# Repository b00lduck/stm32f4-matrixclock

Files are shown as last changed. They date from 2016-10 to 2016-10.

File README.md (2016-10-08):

# stm32f4-matrixclock
Use the STM32F4 to drive a large LED matrix with TLC5940

### Port mapping:

 - PA8  GSCLK	common PWM-clock for the TLC5940s    (TIM1 AF1)

 - PC6  BLANK   common BLANK-signal for the TLC5940s (TIM3 AF2)
 - PC7  LATCH   common LATCH-signal for the TLC5940s (TIM3 AF2)
 - PC9  SCK     common LATCH-signal for the TLC5940s (TIM8 AF3)

 - PD12 LED4	discovery board
 - PD13 LED3	discovery board
 - PD14 LED5	discovery board
 - PD15 LED6  	discovery board

 - PE0  SDA_A	Sector A data (DMA)
 - PE1  SDA_B	Sector B data (DMA)
 - PE2  SDA_C	Sector C data (DMA)
 - PE3  SDA_D	Sector D data (DMA)
 - PE4  SDA_E	Sector E data (DMA)
 - PE5  SDA_F	Sector F data (DMA)
 - PE6  SDA_G	Sector G data (DMA)
 - PE7  SDA_H	Sector H data (DMA)

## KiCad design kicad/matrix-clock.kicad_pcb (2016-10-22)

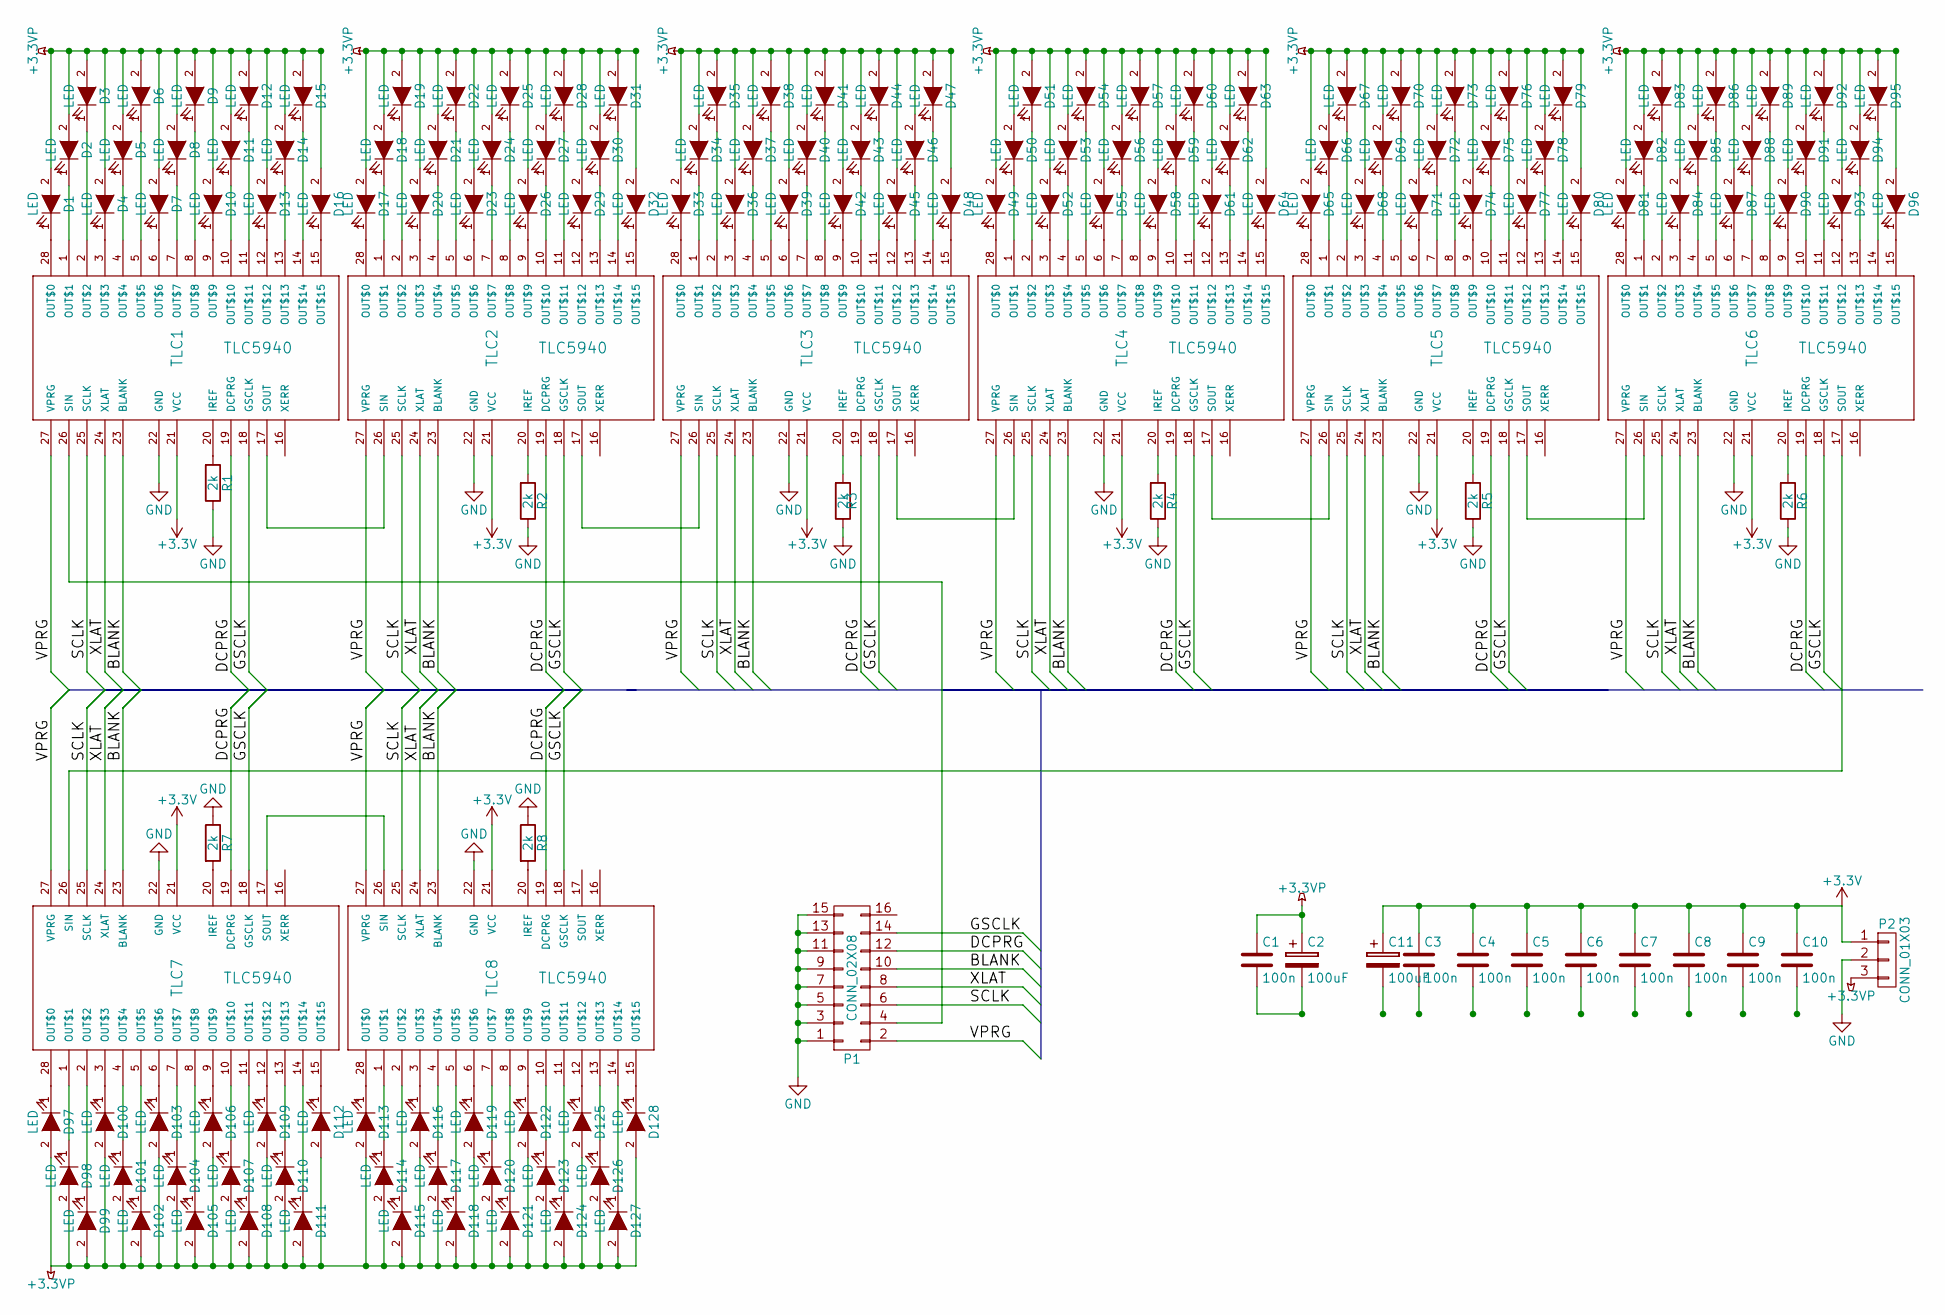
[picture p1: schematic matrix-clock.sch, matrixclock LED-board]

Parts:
C1: 100n; C_0603_HandSoldering
C2, C11: 100uF; TantalC_SizeX_EIA-7343
C3, C4, C5, C6, C7, C8, C9, C10: 100n; C_Disc_D3_P2.5
D1, D2, D3, D4, D5, D6, D7, D8, D9, D10, D11, D12, D13, D14, D15, D16, D17, D18, D19, D20, D21, D22, D23, D24, D25, D26, D27, D28, D29, D30, D31, D32, D33, D34, D35, D36, D37, D38, D39, D40, D41, D42, D43, D44, D45, D46, D47, D48, D49, D50, D51, D52, D53, D54, D55, D56, D57, D58, D59, D60, D61, D62, D63, D64, D65, D66, D67, D68, D69, D70, D71, D72, D73, D74, D75, D76, D77, D78, D79, D80, D81, D82, D83, D84, D85, D86, D87, D88, D89, D90, D91, D92, D93, D94, D95, D96, D97, D98, D99, D100, D101, D102, D103, D104, D105, D106, D107, D108, D109, D110, D111, D112, D113, D114, D115, D116, D117, D118, D119, D120, D121, D122, D123, D124, D125, D126, D127, D128: LED; MENTOR 50.046
P1: CONN_02X08; Pin_Header_Straight_2x08
P2: CONN_01X03; Pin_Header_Straight_1x03
R1, R2, R3, R4, R5, R6, R7, R8: 2k; R_1206_HandSoldering
TLC1, TLC2, TLC3, TLC4, TLC5, TLC6, TLC7, TLC8: TLC5940; TLC5940-HTSSOP-28

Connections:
+3.3VP: C1.1, C2.1, D1.2 (A), D2.2 (A), D3.2 (A), D4.2 (A), D5.2 (A), D6.2 (A), D7.2 (A), D8.2 (A), D9.2 (A), D10.2 (A), D11.2 (A), D12.2 (A), D13.2 (A), D14.2 (A), D15.2 (A), D16.2 (A), D17.2 (A), D18.2 (A), D19.2 (A), D20.2 (A), D21.2 (A), D22.2 (A), D23.2 (A), D24.2 (A), D25.2 (A), D26.2 (A), D27.2 (A), D28.2 (A), D29.2 (A), D30.2 (A), D31.2 (A), D32.2 (A), D33.2 (A), D34.2 (A), D35.2 (A), D36.2 (A), D37.2 (A), D38.2 (A), D39.2 (A), D40.2 (A), D41.2 (A), D42.2 (A), D43.2 (A), D44.2 (A), D45.2 (A), D46.2 (A), D47.2 (A), D48.2 (A), D49.2 (A), D50.2 (A), D51.2 (A), D52.2 (A), D53.2 (A), D54.2 (A), D55.2 (A), D56.2 (A), D57.2 (A), D58.2 (A), D59.2 (A), D60.2 (A), D61.2 (A), D62.2 (A), D63.2 (A), D64.2 (A), D65.2 (A), D66.2 (A), D67.2 (A), D68.2 (A), D69.2 (A), D70.2 (A), D71.2 (A), D72.2 (A), D73.2 (A), D74.2 (A), D75.2 (A), D76.2 (A), D77.2 (A), D78.2 (A), D79.2 (A), D80.2 (A), D81.2 (A), D82.2 (A), D83.2 (A), D84.2 (A), D85.2 (A), D86.2 (A), D87.2 (A), D88.2 (A), D89.2 (A), D90.2 (A), D91.2 (A), D92.2 (A), D93.2 (A), D94.2 (A), D95.2 (A), D96.2 (A), D97.2 (A), D98.2 (A), D99.2 (A), D100.2 (A), D101.2 (A), D102.2 (A), D103.2 (A), D104.2 (A), D105.2 (A), D106.2 (A), D107.2 (A), D108.2 (A), D109.2 (A), D110.2 (A), D111.2 (A), D112.2 (A), D113.2 (A), D114.2 (A), D115.2 (A), D116.2 (A), D117.2 (A), D118.2 (A), D119.2 (A), D120.2 (A), D121.2 (A), D122.2 (A), D123.2 (A), D124.2 (A), D125.2 (A), D126.2 (A), D127.2 (A), D128.2 (A), P2.3
+3V3: C3.1, C4.1, C5.1, C6.1, C7.1, C8.1, C9.1, C10.1, C11.1, P2.1, TLC1.21 (VCC), TLC2.21 (VCC), TLC3.21 (VCC), TLC4.21 (VCC), TLC5.21 (VCC), TLC6.21 (VCC), TLC7.21 (VCC), TLC8.21 (VCC)
/BLANK: P1.10, TLC1.23 (BLANK), TLC2.23 (BLANK), TLC3.23 (BLANK), TLC4.23 (BLANK), TLC5.23 (BLANK), TLC6.23 (BLANK), TLC7.23 (BLANK), TLC8.23 (BLANK)
/DCPRG: P1.12, TLC1.19 (DCPRG), TLC2.19 (DCPRG), TLC3.19 (DCPRG), TLC4.19 (DCPRG), TLC5.19 (DCPRG), TLC6.19 (DCPRG), TLC7.19 (DCPRG), TLC8.19 (DCPRG)
/GSCLK: P1.14, TLC1.18 (GSCLK), TLC2.18 (GSCLK), TLC3.18 (GSCLK), TLC4.18 (GSCLK), TLC5.18 (GSCLK), TLC6.18 (GSCLK), TLC7.18 (GSCLK), TLC8.18 (GSCLK)
/SCLK: P1.6, TLC1.25 (SCLK), TLC2.25 (SCLK), TLC3.25 (SCLK), TLC4.25 (SCLK), TLC5.25 (SCLK), TLC6.25 (SCLK), TLC7.25 (SCLK), TLC8.25 (SCLK)
/VPRG: P1.2, TLC1.27 (VPRG), TLC2.27 (VPRG), TLC3.27 (VPRG), TLC4.27 (VPRG), TLC5.27 (VPRG), TLC6.27 (VPRG), TLC7.27 (VPRG), TLC8.27 (VPRG)
/XLAT: P1.8, TLC1.24 (XLAT), TLC2.24 (XLAT), TLC3.24 (XLAT), TLC4.24 (XLAT), TLC5.24 (XLAT), TLC6.24 (XLAT), TLC7.24 (XLAT), TLC8.24 (XLAT)
unnamed: D1.1 (K), TLC1.28 (OUT$0)
unnamed: D2.1 (K), TLC1.1 (OUT$1)
unnamed: D3.1 (K), TLC1.2 (OUT$2)
unnamed: D4.1 (K), TLC1.3 (OUT$3)
unnamed: D5.1 (K), TLC1.4 (OUT$4)
unnamed: D6.1 (K), TLC1.5 (OUT$5)
unnamed: D7.1 (K), TLC1.6 (OUT$6)
unnamed: D8.1 (K), TLC1.7 (OUT$7)
unnamed: D9.1 (K), TLC1.8 (OUT$8)
unnamed: D10.1 (K), TLC1.9 (OUT$9)
unnamed: D11.1 (K), TLC1.10 (OUT$10)
unnamed: D12.1 (K), TLC1.11 (OUT$11)
unnamed: D13.1 (K), TLC1.12 (OUT$12)
unnamed: D14.1 (K), TLC1.13 (OUT$13)
unnamed: D15.1 (K), TLC1.14 (OUT$14)
unnamed: D16.1 (K), TLC1.15 (OUT$15)
unnamed: D17.1 (K), TLC2.28 (OUT$0)
unnamed: D18.1 (K), TLC2.1 (OUT$1)
unnamed: D19.1 (K), TLC2.2 (OUT$2)
unnamed: D20.1 (K), TLC2.3 (OUT$3)
unnamed: D21.1 (K), TLC2.4 (OUT$4)
unnamed: D22.1 (K), TLC2.5 (OUT$5)
unnamed: D23.1 (K), TLC2.6 (OUT$6)
unnamed: D24.1 (K), TLC2.7 (OUT$7)
unnamed: D25.1 (K), TLC2.8 (OUT$8)
unnamed: D26.1 (K), TLC2.9 (OUT$9)
unnamed: D27.1 (K), TLC2.10 (OUT$10)
unnamed: D28.1 (K), TLC2.11 (OUT$11)
unnamed: D29.1 (K), TLC2.12 (OUT$12)
unnamed: D30.1 (K), TLC2.13 (OUT$13)
unnamed: D31.1 (K), TLC2.14 (OUT$14)
unnamed: D32.1 (K), TLC2.15 (OUT$15)
unnamed: D33.1 (K), TLC3.28 (OUT$0)
unnamed: D34.1 (K), TLC3.1 (OUT$1)
unnamed: D35.1 (K), TLC3.2 (OUT$2)
unnamed: D36.1 (K), TLC3.3 (OUT$3)
unnamed: D37.1 (K), TLC3.4 (OUT$4)
unnamed: D38.1 (K), TLC3.5 (OUT$5)
unnamed: D39.1 (K), TLC3.6 (OUT$6)
unnamed: D40.1 (K), TLC3.7 (OUT$7)
unnamed: D41.1 (K), TLC3.8 (OUT$8)
unnamed: D42.1 (K), TLC3.9 (OUT$9)
unnamed: D43.1 (K), TLC3.10 (OUT$10)
unnamed: D44.1 (K), TLC3.11 (OUT$11)
unnamed: D45.1 (K), TLC3.12 (OUT$12)
unnamed: D46.1 (K), TLC3.13 (OUT$13)
unnamed: D47.1 (K), TLC3.14 (OUT$14)
unnamed: D48.1 (K), TLC3.15 (OUT$15)
unnamed: D49.1 (K), TLC4.28 (OUT$0)
unnamed: D50.1 (K), TLC4.1 (OUT$1)
unnamed: D51.1 (K), TLC4.2 (OUT$2)
unnamed: D52.1 (K), TLC4.3 (OUT$3)
unnamed: D53.1 (K), TLC4.4 (OUT$4)
unnamed: D54.1 (K), TLC4.5 (OUT$5)
unnamed: D55.1 (K), TLC4.6 (OUT$6)
unnamed: D56.1 (K), TLC4.7 (OUT$7)
unnamed: D57.1 (K), TLC4.8 (OUT$8)
unnamed: D58.1 (K), TLC4.9 (OUT$9)
unnamed: D59.1 (K), TLC4.10 (OUT$10)
unnamed: D60.1 (K), TLC4.11 (OUT$11)
unnamed: D61.1 (K), TLC4.12 (OUT$12)
unnamed: D62.1 (K), TLC4.13 (OUT$13)
unnamed: D63.1 (K), TLC4.14 (OUT$14)
unnamed: D64.1 (K), TLC4.15 (OUT$15)
unnamed: D65.1 (K), TLC5.28 (OUT$0)
unnamed: D66.1 (K), TLC5.1 (OUT$1)
unnamed: D67.1 (K), TLC5.2 (OUT$2)
unnamed: D68.1 (K), TLC5.3 (OUT$3)
unnamed: D69.1 (K), TLC5.4 (OUT$4)
unnamed: D70.1 (K), TLC5.5 (OUT$5)
unnamed: D71.1 (K), TLC5.6 (OUT$6)
unnamed: D72.1 (K), TLC5.7 (OUT$7)
unnamed: D73.1 (K), TLC5.8 (OUT$8)
unnamed: D74.1 (K), TLC5.9 (OUT$9)
unnamed: D75.1 (K), TLC5.10 (OUT$10)
unnamed: D76.1 (K), TLC5.11 (OUT$11)
unnamed: D77.1 (K), TLC5.12 (OUT$12)
unnamed: D78.1 (K), TLC5.13 (OUT$13)
unnamed: D79.1 (K), TLC5.14 (OUT$14)
unnamed: D80.1 (K), TLC5.15 (OUT$15)
unnamed: D81.1 (K), TLC6.28 (OUT$0)
unnamed: D82.1 (K), TLC6.1 (OUT$1)
unnamed: D83.1 (K), TLC6.2 (OUT$2)
unnamed: D84.1 (K), TLC6.3 (OUT$3)
unnamed: D85.1 (K), TLC6.4 (OUT$4)
unnamed: D86.1 (K), TLC6.5 (OUT$5)
unnamed: D87.1 (K), TLC6.6 (OUT$6)
unnamed: D88.1 (K), TLC6.7 (OUT$7)
unnamed: D89.1 (K), TLC6.8 (OUT$8)
unnamed: D90.1 (K), TLC6.9 (OUT$9)
unnamed: D91.1 (K), TLC6.10 (OUT$10)
unnamed: D92.1 (K), TLC6.11 (OUT$11)
unnamed: D93.1 (K), TLC6.12 (OUT$12)
unnamed: D94.1 (K), TLC6.13 (OUT$13)
unnamed: D95.1 (K), TLC6.14 (OUT$14)
unnamed: D96.1 (K), TLC6.15 (OUT$15)
unnamed: D97.1 (K), TLC7.28 (OUT$0)
unnamed: D98.1 (K), TLC7.1 (OUT$1)
unnamed: D99.1 (K), TLC7.2 (OUT$2)
unnamed: D100.1 (K), TLC7.3 (OUT$3)
unnamed: D101.1 (K), TLC7.4 (OUT$4)
unnamed: D102.1 (K), TLC7.5 (OUT$5)
unnamed: D103.1 (K), TLC7.6 (OUT$6)
unnamed: D104.1 (K), TLC7.7 (OUT$7)
unnamed: D105.1 (K), TLC7.8 (OUT$8)
unnamed: D106.1 (K), TLC7.9 (OUT$9)
unnamed: D107.1 (K), TLC7.10 (OUT$10)
unnamed: D108.1 (K), TLC7.11 (OUT$11)
unnamed: D109.1 (K), TLC7.12 (OUT$12)
unnamed: D110.1 (K), TLC7.13 (OUT$13)
unnamed: D111.1 (K), TLC7.14 (OUT$14)
unnamed: D112.1 (K), TLC7.15 (OUT$15)
unnamed: D113.1 (K), TLC8.28 (OUT$0)
unnamed: D114.1 (K), TLC8.1 (OUT$1)
unnamed: D115.1 (K), TLC8.2 (OUT$2)
unnamed: D116.1 (K), TLC8.3 (OUT$3)
unnamed: D117.1 (K), TLC8.4 (OUT$4)
unnamed: D118.1 (K), TLC8.5 (OUT$5)
unnamed: D119.1 (K), TLC8.6 (OUT$6)
unnamed: D120.1 (K), TLC8.7 (OUT$7)
unnamed: D121.1 (K), TLC8.8 (OUT$8)
unnamed: D122.1 (K), TLC8.9 (OUT$9)
unnamed: D123.1 (K), TLC8.10 (OUT$10)
unnamed: D124.1 (K), TLC8.11 (OUT$11)
unnamed: D125.1 (K), TLC8.12 (OUT$12)
unnamed: D126.1 (K), TLC8.13 (OUT$13)
unnamed: D127.1 (K), TLC8.14 (OUT$14)
unnamed: D128.1 (K), TLC8.15 (OUT$15)
unnamed: P1.4, TLC1.26 (SIN)
unnamed: R1.2, TLC1.20 (IREF)
unnamed: R2.2, TLC2.20 (IREF)
unnamed: R3.2, TLC3.20 (IREF)
unnamed: R4.2, TLC4.20 (IREF)
unnamed: R5.2, TLC5.20 (IREF)
unnamed: R6.2, TLC6.20 (IREF)
unnamed: R7.2, TLC7.20 (IREF)
unnamed: R8.2, TLC8.20 (IREF)
unnamed: TLC1.17 (SOUT), TLC2.26 (SIN)
unnamed: TLC2.17 (SOUT), TLC3.26 (SIN)
unnamed: TLC3.17 (SOUT), TLC4.26 (SIN)
unnamed: TLC4.17 (SOUT), TLC5.26 (SIN)
unnamed: TLC5.17 (SOUT), TLC6.26 (SIN)
unnamed: TLC6.17 (SOUT), TLC7.26 (SIN)
unnamed: TLC7.17 (SOUT), TLC8.26 (SIN)

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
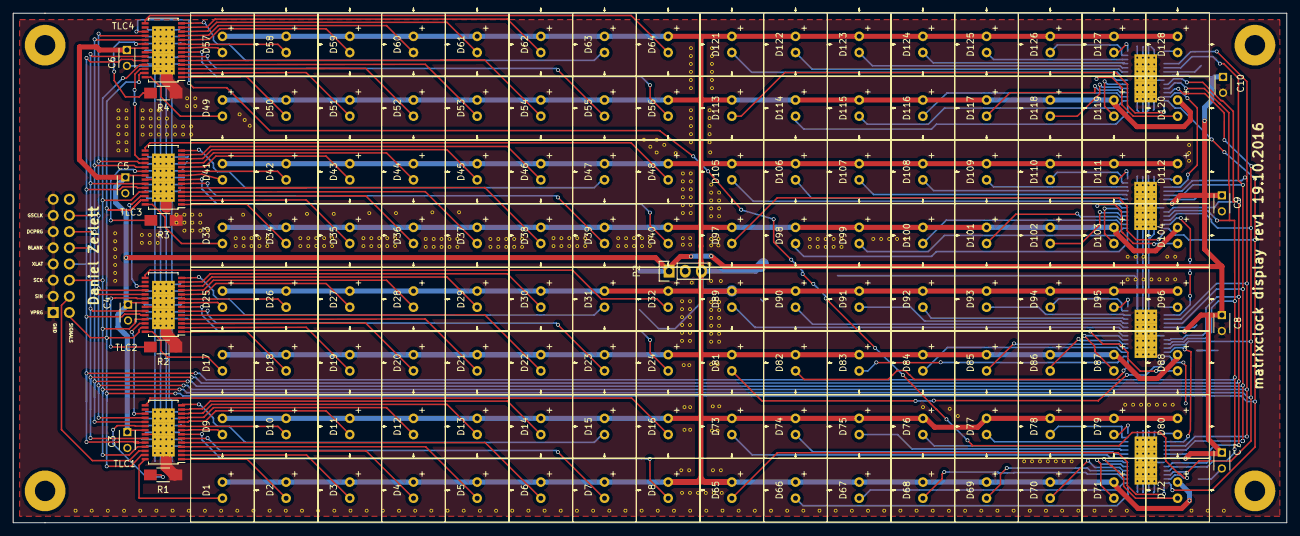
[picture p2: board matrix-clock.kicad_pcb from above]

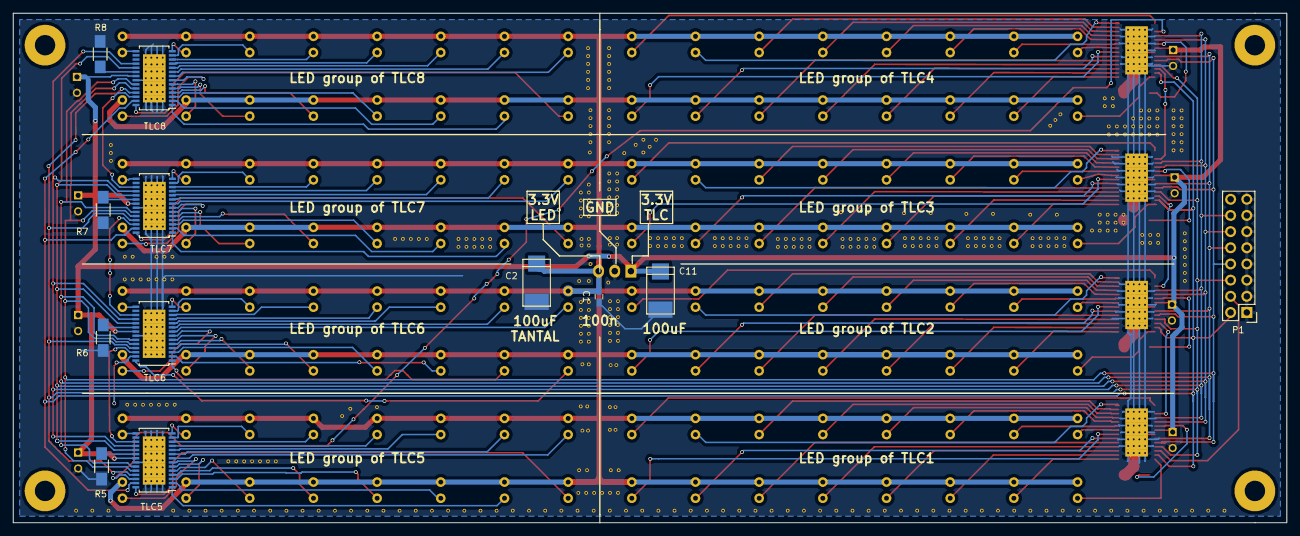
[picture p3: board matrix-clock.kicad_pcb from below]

Board: 2 copper layers, 200.0 x 80.0 mm, 157 parts (12 on the bottom side), 153 nets.

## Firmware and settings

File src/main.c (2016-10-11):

#include "main.h"
#include "stm32f4xx_dbgmcu.h"
#include "tlc5940/videoram.h"
#include "tlc5940/driver.h"

void init() {

    // Initialize LEDS GPIO
    // SysTick_Config(SystemCoreClock / 1000);
    STM_EVAL_LEDInit(LED3);
    STM_EVAL_LEDInit(LED4);
    STM_EVAL_LEDInit(LED5);
    STM_EVAL_LEDInit(LED6);

    // Initialize button GPIO
    //STM_EVAL_PBInit(BUTTON_USER, BUTTON_MODE_EXTI);

    // Timer stop on debug
    #ifdef STOP_TIMER_ON_DEBUG
	DBGMCU_APB1PeriphConfig(DBGMCU_TIM1_STOP,ENABLE);
	DBGMCU_APB1PeriphConfig(DBGMCU_TIM8_STOP,ENABLE);
	DBGMCU_Config(DBGMCU_TIM3_STOP,ENABLE);
    #endif

	memset(vram, 0x00, VIDEORAMSIZE * 2);

	tlc5940_init();

}


int main(void) {

	init();

	// mainloop (TM)
	while (1) {

		while (frameStart == 0) {
			STM_EVAL_LEDOff(LED3);
		}

		STM_EVAL_LEDOn(LED3);

		convertFrame();

		STM_EVAL_LEDOff(LED3);

		frameStart = 0;

	}

}

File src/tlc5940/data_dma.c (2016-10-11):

#include "data_dma.h"
#include "stm32f4xx.h"
#include "stm32f4xx_gpio.h"
#include "stm32f4xx_tim.h"
#include "stm32f4xx_rcc.h"
#include "stm32f4xx_dma.h"
#include "videoram.h"
#include "timing.h"


void data_dma_init() {

	GPIO_InitTypeDef GPIO_InitStructure;

	// GPIO clock
	RCC_AHB1PeriphClockCmd(SIG_DATA_PORT_CLOCK, ENABLE);

	// GPIO
	GPIO_InitStructure.GPIO_Pin = GPIO_Pin_0 | GPIO_Pin_1 | GPIO_Pin_2 | GPIO_Pin_3 | GPIO_Pin_4 | GPIO_Pin_5 | GPIO_Pin_6 | GPIO_Pin_7;
	GPIO_InitStructure.GPIO_Mode = GPIO_Mode_OUT;
	GPIO_InitStructure.GPIO_Speed = GPIO_Speed_100MHz;
	GPIO_InitStructure.GPIO_OType = GPIO_OType_PP;
	GPIO_InitStructure.GPIO_PuPd = GPIO_PuPd_NOPULL ;
	GPIO_Init(SIG_DATA_PORT, &GPIO_InitStructure);

	// GPIO clock enable
	RCC_AHB1PeriphClockCmd(SIG_DATACLOCK_PORT_CLOCK, ENABLE);

	// GPIO configuration
	GPIO_InitStructure.GPIO_Pin = SIG_DATACLOCK_PIN;
	GPIO_InitStructure.GPIO_Mode = GPIO_Mode_AF;
	GPIO_InitStructure.GPIO_Speed = GPIO_Speed_100MHz;
	GPIO_InitStructure.GPIO_OType = GPIO_OType_PP;
	GPIO_InitStructure.GPIO_PuPd = GPIO_PuPd_NOPULL;
	GPIO_Init(SIG_DATACLOCK_PORT, &GPIO_InitStructure);

	// Connect pin to alternate function of TIM8
	GPIO_PinAFConfig(SIG_DATACLOCK_PORT, SIG_DATACLOCK_PINSOURCE, SIG_DATACLOCK_PIN_AF);


	DMA_InitTypeDef  DMA_InitStructure;
	TIM_TimeBaseInitTypeDef  TIM_TimeBaseStructure;
	TIM_OCInitTypeDef  TIM_OCInitStructure;
	NVIC_InitTypeDef NVIC_InitStructure;

	// Enable Timer Clock
	RCC_APB2PeriphClockCmd(SIG_DATA_TIMER_CLOCK, ENABLE);

	// Enable DMA Clock
	RCC_AHB1PeriphClockCmd(SIG_DATA_STREAM_CLOCK, ENABLE);

	// Time base configuration
	TIM_TimeBaseStructure.TIM_Prescaler = TIM_ICPSC_DIV1;
	TIM_TimeBaseStructure.TIM_CounterMode = TIM_CounterMode_Up;
	TIM_TimeBaseStructure.TIM_Period = DMA_PERIOD;
	TIM_TimeBaseStructure.TIM_ClockDivision = TIM_CKD_DIV1;
	TIM_TimeBaseStructure.TIM_RepetitionCounter = 0;
	TIM_TimeBaseInit(SIG_DATA_TIMER, &TIM_TimeBaseStructure);

	// Be a slave of TIM1
	TIM_SelectInputTrigger(SIG_DATA_TIMER, TIM_TS_ITR0);
    TIM_SelectSlaveMode(SIG_DATA_TIMER, TIM_SlaveMode_Trigger);
    TIM_SelectMasterSlaveMode(SIG_DATA_TIMER, TIM_MasterSlaveMode_Enable);


    // SCK output: PWM1 Mode configuration: Channel3
	TIM_OCInitStructure.TIM_OCMode = TIM_OCMode_PWM2;
	TIM_OCInitStructure.TIM_OutputState = TIM_OutputState_Enable;
	TIM_OCInitStructure.TIM_OutputNState = TIM_OutputNState_Disable;
	TIM_OCInitStructure.TIM_Pulse = (DMA_PERIOD >> 1) - 1;
	TIM_OCInitStructure.TIM_OCPolarity = TIM_OCPolarity_High;
	TIM_OCInitStructure.TIM_OCIdleState = TIM_OCIdleState_Reset;
    TIM_OC4Init(SIG_DATA_TIMER, &TIM_OCInitStructure);

	// Main Output Enable
	TIM_CtrlPWMOutputs(SIG_DATA_TIMER, ENABLE);

	// use timer update trigger for pixel DMA
	TIM_DMACmd(SIG_DATA_TIMER, TIM_DMA_Update, ENABLE);

	// Configure DMA Stream
	DMA_InitStructure.DMA_Channel = SIG_DATA_CHANNEL;
	DMA_InitStructure.DMA_PeripheralBaseAddr = ((uint32_t)&SIG_DATA_PORT->ODR);
	DMA_InitStructure.DMA_Memory0BaseAddr = (uint32_t)vram;
	DMA_InitStructure.DMA_DIR = DMA_DIR_MemoryToPeripheral;
	DMA_InitStructure.DMA_BufferSize = BUFFERSIZE;
	DMA_InitStructure.DMA_PeripheralInc = DMA_PeripheralInc_Disable;
	DMA_InitStructure.DMA_MemoryInc = DMA_MemoryInc_Enable;
	DMA_InitStructure.DMA_PeripheralDataSize = DMA_PeripheralDataSize_Byte;
	DMA_InitStructure.DMA_MemoryDataSize = DMA_MemoryDataSize_Byte;
	DMA_InitStructure.DMA_Mode = DMA_Mode_Normal;
	DMA_InitStructure.DMA_Priority = DMA_Priority_VeryHigh;
	DMA_InitStructure.DMA_FIFOMode = DMA_FIFOMode_Disable;
	DMA_InitStructure.DMA_FIFOThreshold = DMA_FIFOThreshold_Full;
	DMA_InitStructure.DMA_MemoryBurst = DMA_MemoryBurst_Single;
	DMA_InitStructure.DMA_PeripheralBurst = DMA_PeripheralBurst_Single;
	DMA_Init(SIG_DATA_STREAM, &DMA_InitStructure);

    DMA_Cmd(SIG_DATA_STREAM, DISABLE);


    // Enable DMA Stream Transfer Complete interrupt
    DMA_ITConfig(SIG_DATA_STREAM, DMA_IT_TCIF1, ENABLE);

    // Enable the global Interrupt
    NVIC_InitStructure.NVIC_IRQChannel = SIG_DATA_STREAM_IRQ;
    NVIC_InitStructure.NVIC_IRQChannelPreemptionPriority = 15;
    NVIC_InitStructure.NVIC_IRQChannelSubPriority = 15;
    NVIC_InitStructure.NVIC_IRQChannelCmd = ENABLE;
    NVIC_Init(&NVIC_InitStructure);
}


void DMA2_Stream1_IRQHandler(void) {

	// Clear interrupt flag.
	DMA2->LIFCR |= DMA_LIFCR_CTCIF1;

	// blank out
	SIG_DATA_PORT->ODR = 0x00;

	// disable the timer
	SIG_DATA_TIMER->CR1 &= ~TIM_CR1_CEN;
}

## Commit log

2016-10-07 BLANK signal generation via TIM1 72Hz
2016-10-08 tighten timing
2016-10-08 DMA output
2016-10-10 added schematics and board for display
    [matrix-clock.kicad_pcb, matrix-clock.sch]
2016-10-14 board layout
    [_saved_matrix-clock.sch, matrix-clock-B.kicad_pcb, matrix-clock.kicad_pcb]
2016-10-14 layout changes
    [matrix-clock.kicad_pcb]
2016-10-15 finalized board
    [matrix-clock.kicad_pcb]
2016-10-15 moved gerber files
2016-10-15 added gerber
    [matrix-clock-B.Cu.gbr, matrix-clock-B.Mask.gbr, matrix-clock-B.SilkS.gbr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]
2016-10-15 production files
    [matrixclock.GBL, matrixclock.GBO, matrixclock.GBS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]
2016-10-17 removed lib
    [_saved_matrix-clock.sch]
2016-10-19 removed libs
    [matrix-clock.sch]
2016-10-19 pcb fixes
    [matrix-clock.kicad_pcb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]
2016-10-22 modified board
    [matrix-clock.kicad_pcb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]
